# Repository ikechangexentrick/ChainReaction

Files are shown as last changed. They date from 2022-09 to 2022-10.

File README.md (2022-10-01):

# ChainReaction
8 step analog sequencer, including two variants of CV and Trigger.

## ChainReaction-Trigger

front view

### [schematic](https://raw.githubusercontent.com/ikechangexentrick/ChainReaction/master/ChainReaction_Trigger_v1.1_schematic.pdf)

## ChainReaction-CV

front view

### [schematic](https://raw.githubusercontent.com/ikechangexentrick/ChainReaction/master/ChainReaction_CV_v1.1_schematic.pdf)

# TBD

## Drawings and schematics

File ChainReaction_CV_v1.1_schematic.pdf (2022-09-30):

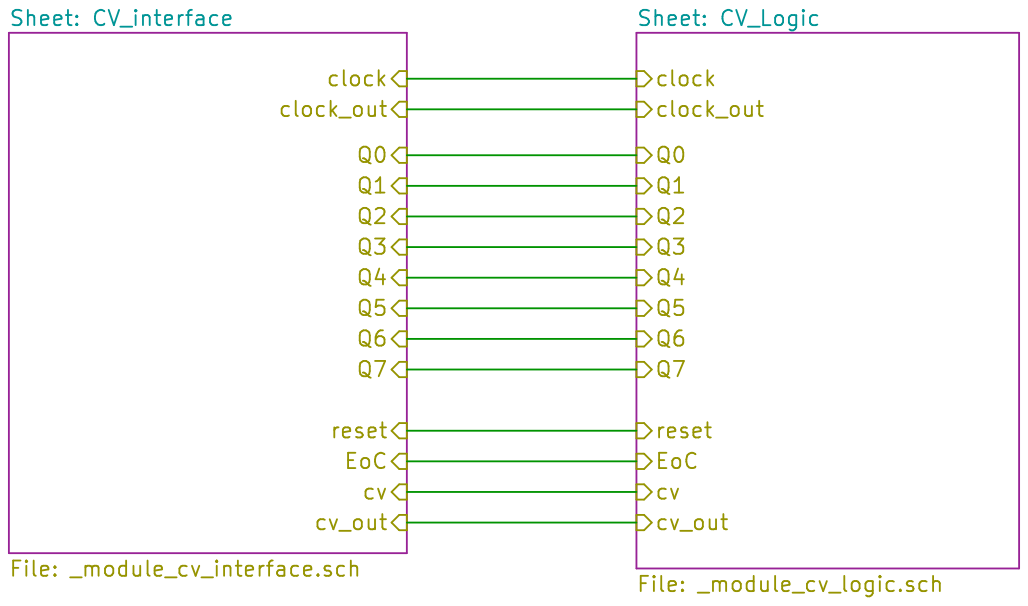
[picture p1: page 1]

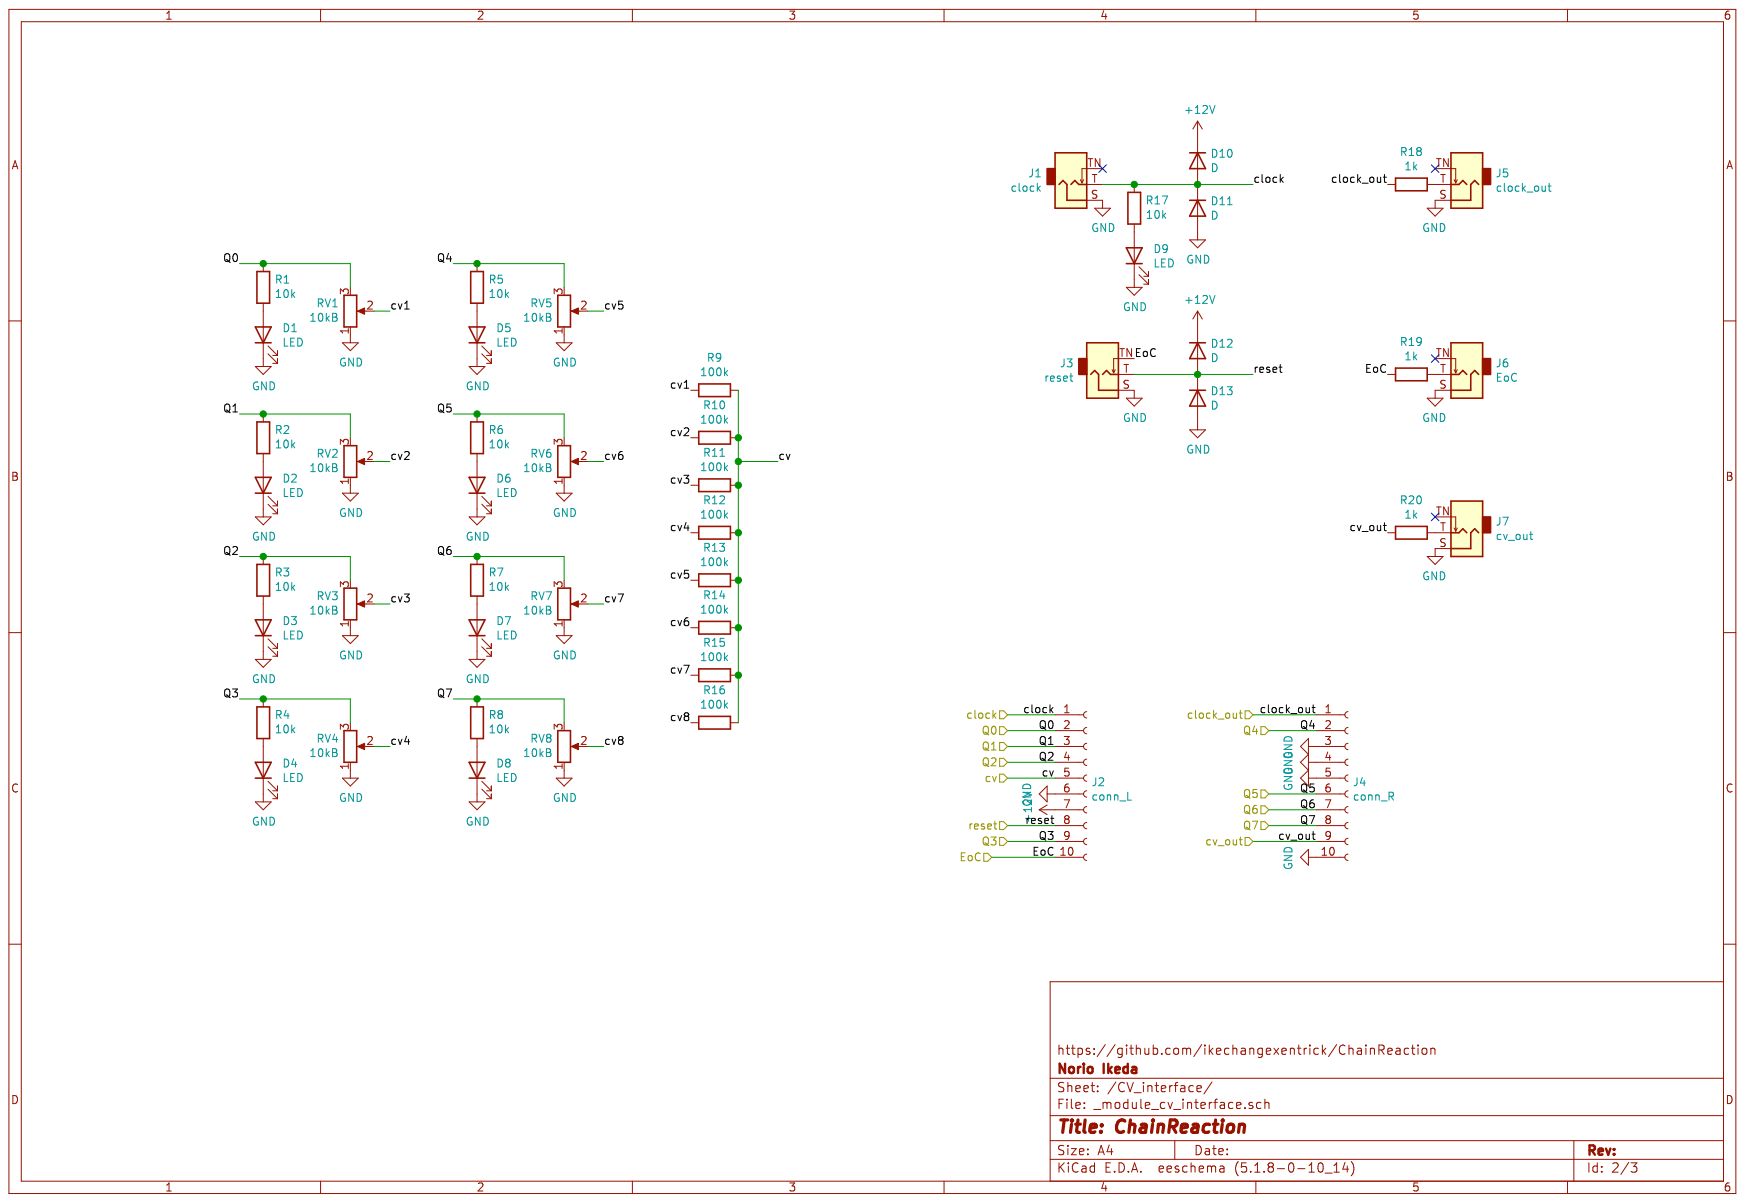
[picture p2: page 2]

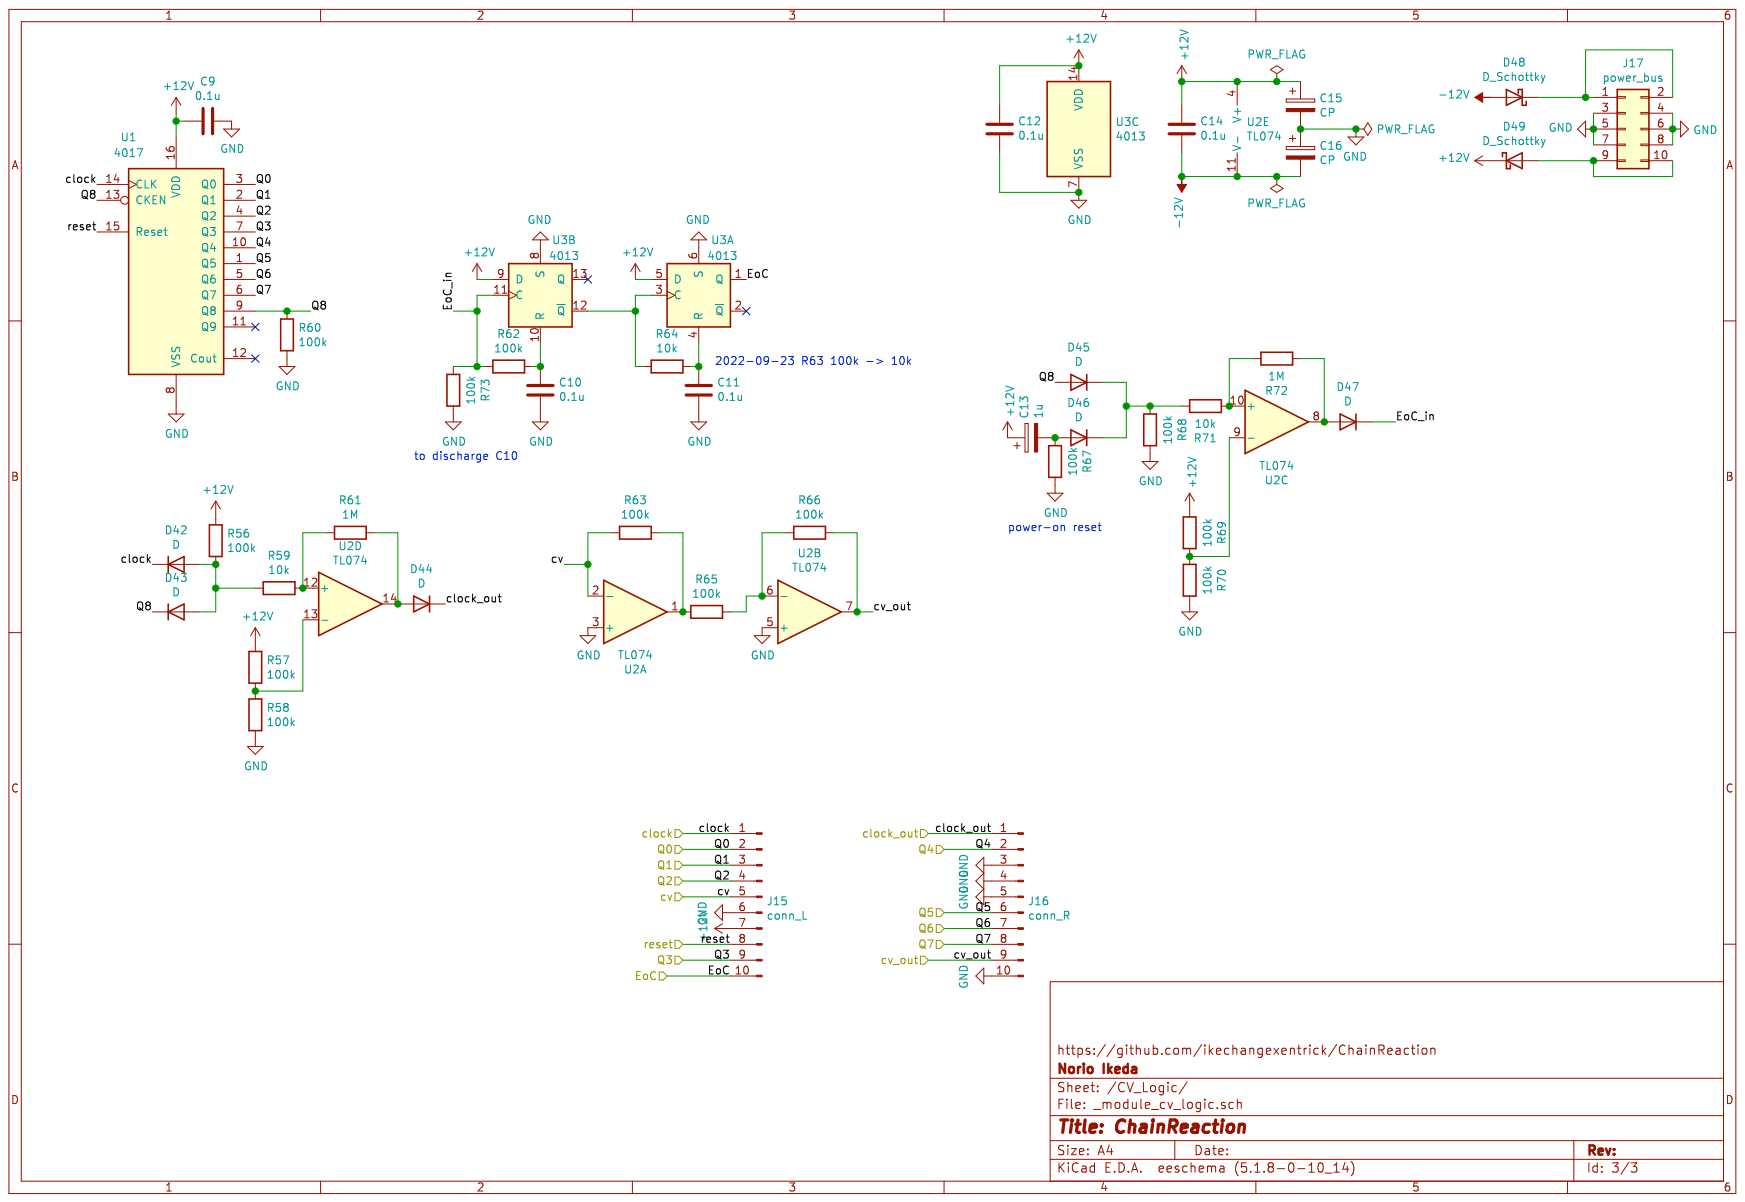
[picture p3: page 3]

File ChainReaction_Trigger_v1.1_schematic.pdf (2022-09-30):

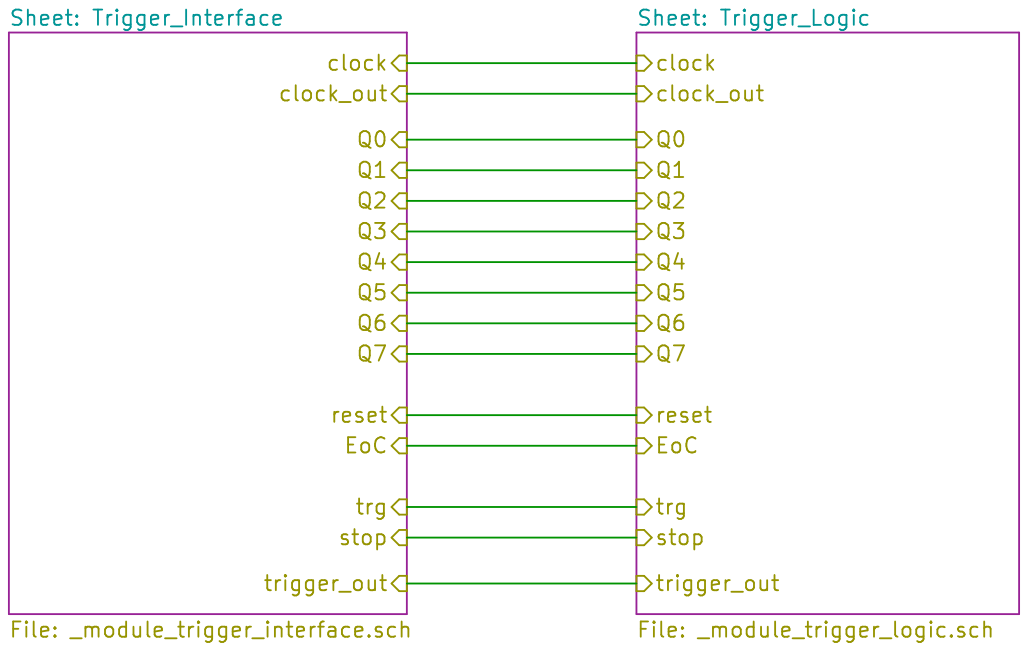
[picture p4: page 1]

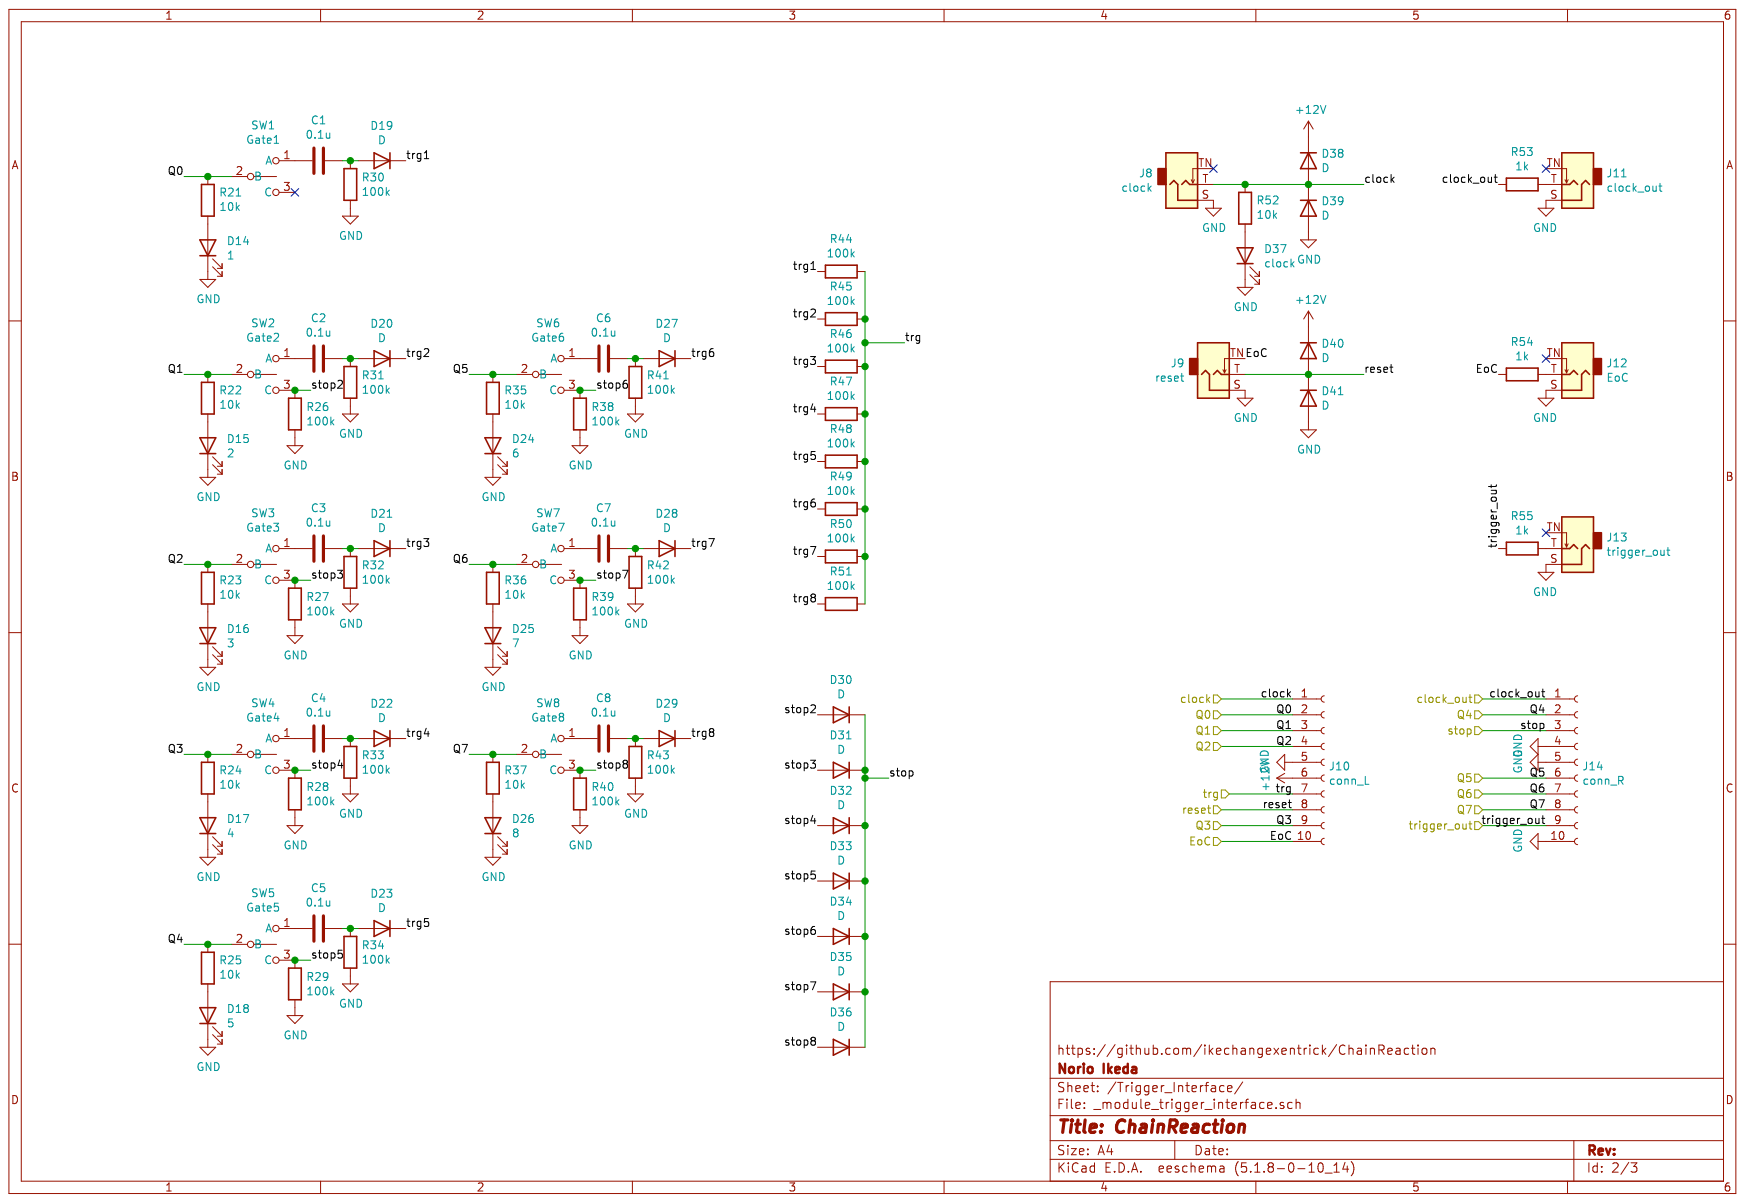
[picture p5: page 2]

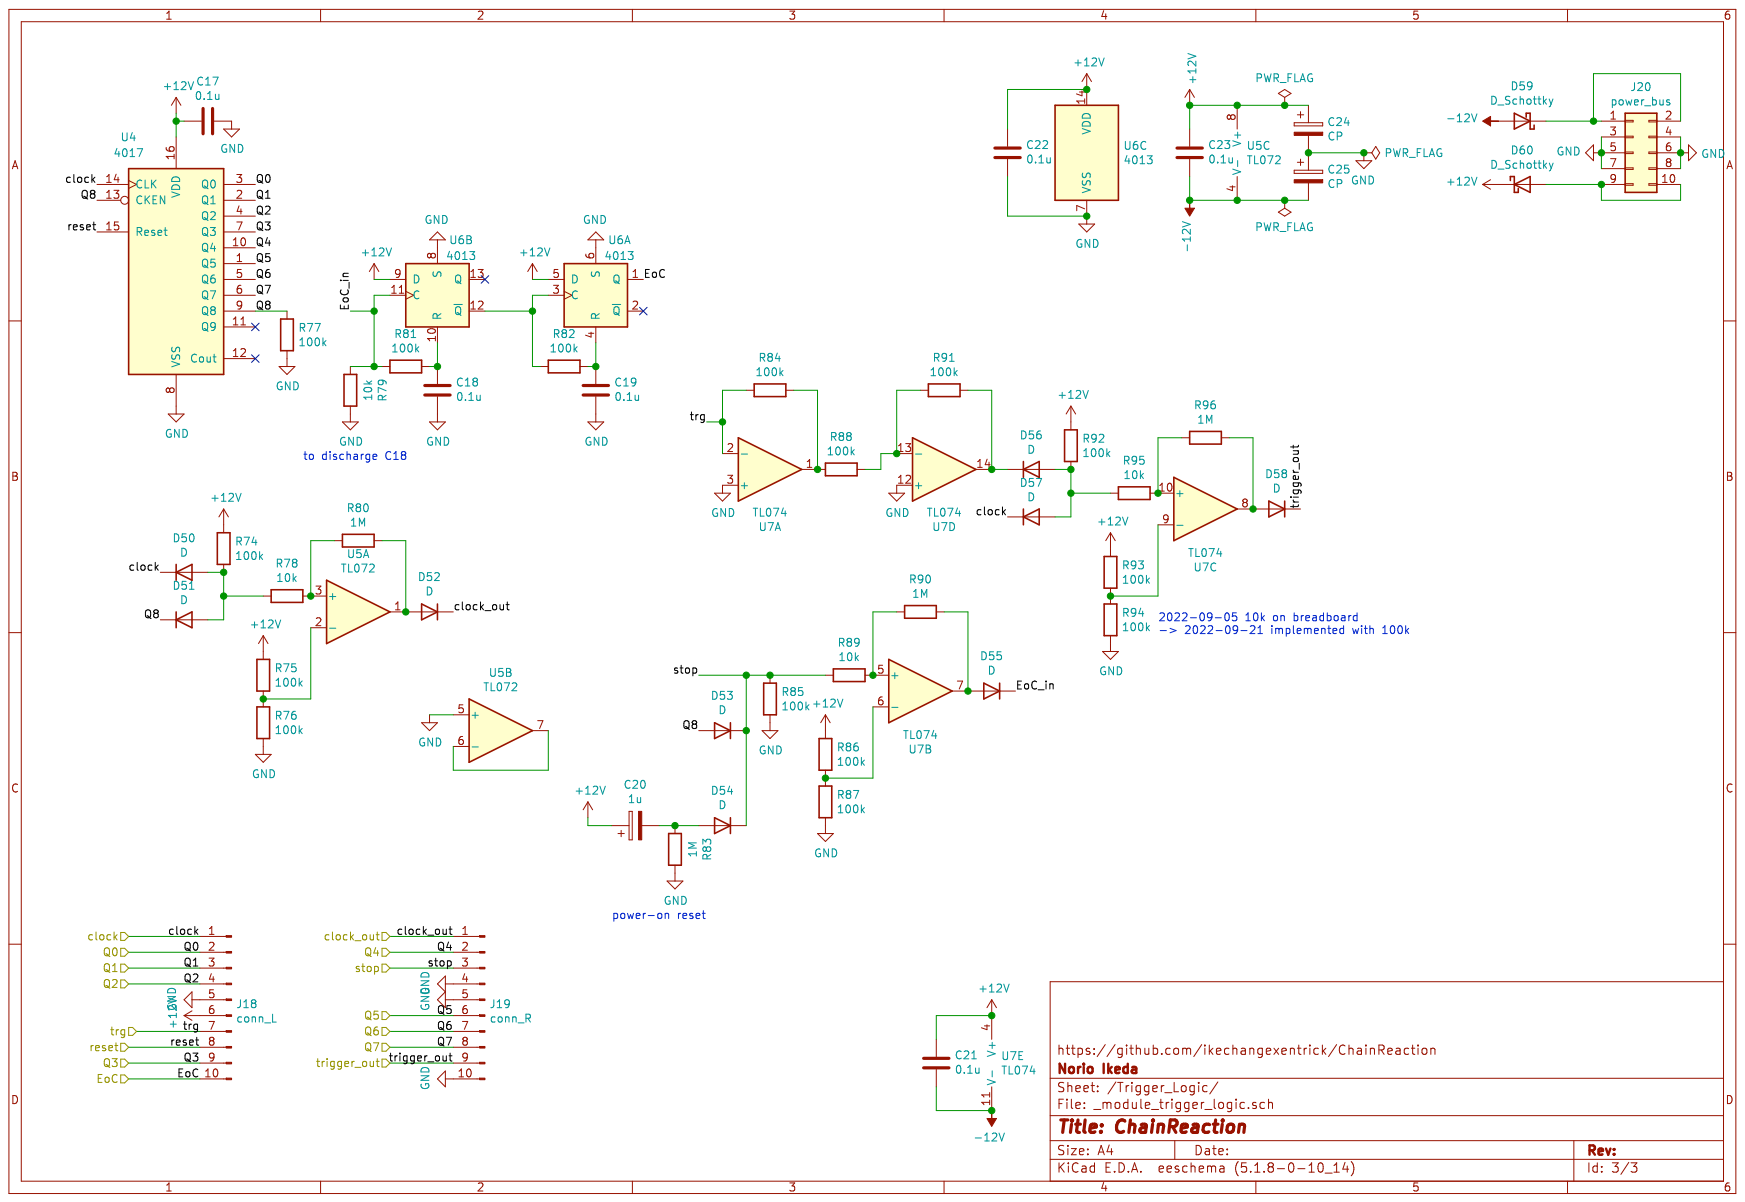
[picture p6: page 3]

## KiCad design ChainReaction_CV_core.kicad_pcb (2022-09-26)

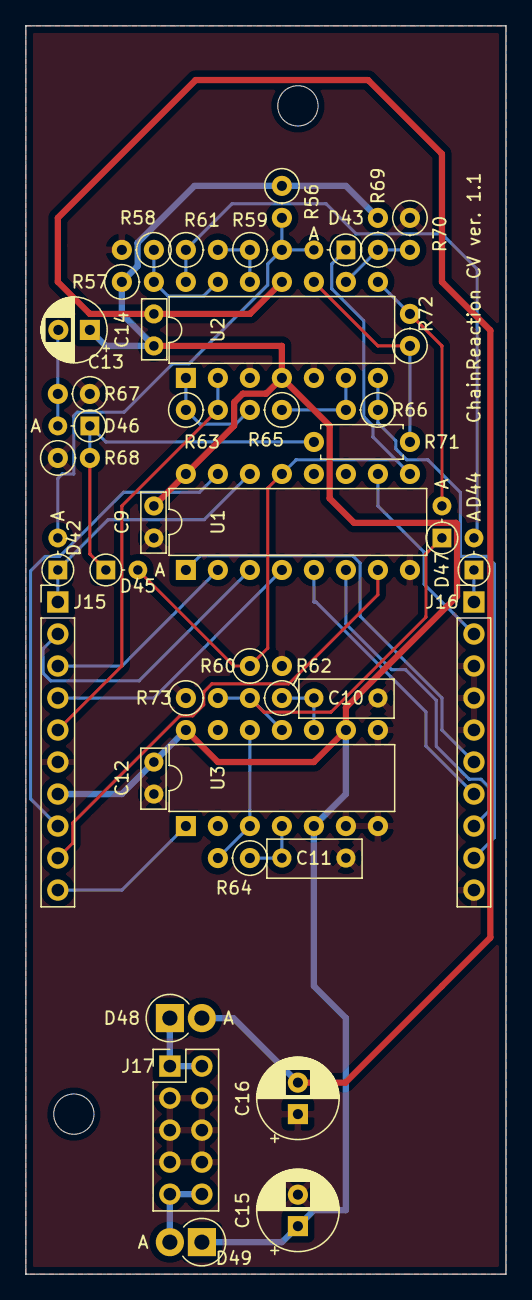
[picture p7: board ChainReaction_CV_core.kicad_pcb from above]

Board: 2 copper layers, 38.1 x 99.1 mm, 40 parts (0 on the bottom side), 35 nets.

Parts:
C9, C12, C14: 0.1u; C_Axial_L4.8mm_D2.0mm_P2.54mm_Horizontal
C10, C11: 0.1u; C_Axial_L4.8mm_D3.1mm_P5.08mm_Horizontal
C13: 1u; CP_Radial_D5.0mm_P2.50mm
C15, C16: CP; CP_Radial_D6.3mm_P2.50mm
D42, D43, D44, D45, D46, D47: D; D_DO-34_SOD68_P2.54mm_Vertical_AnodeUp
D48, D49: D_Schottky; D_DO-15_P2.54mm_Vertical_AnodeUp
J15: conn_L; PinHeader_1x10_P2.54mm_Vertical
J16: conn_R; PinHeader_1x10_P2.54mm_Vertical
J17: power_bus; PinHeader_2x05_P2.54mm_Vertical
R56, R57, R58, R60, R62, R63, R65, R66, R67, R68, R69, R70, R73: 100k; R_Axial_DIN0207_L6.3mm_D2.5mm_P2.54mm_Vertical
R59, R64: 10k; R_Axial_DIN0207_L6.3mm_D2.5mm_P2.54mm_Vertical
R61, R72: 1M; R_Axial_DIN0207_L6.3mm_D2.5mm_P2.54mm_Vertical
R71: 10k; R_Axial_DIN0207_L6.3mm_D2.5mm_P7.62mm_Horizontal
U1: 4017; DIP-16_W7.62mm
U2: TL074; DIP-14_W7.62mm
U3: 4013; DIP-14_W7.62mm

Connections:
+12V: C9.2, C12.2, C13.1, C14.2, C15.1, D49.1, J15.7, R56.1, R57.1, R69.2, U1.16, U2.4, U3.5, U3.9, U3.14
-12V: C14.1, C16.2, D48.2, U2.11
/CV_Logic/EoC: J15.10, U3.1
/CV_Logic/EoC_in: D47.1, R62.2, R73.2, U3.11
/CV_Logic/Q0: J15.2, U1.3
/CV_Logic/Q1: J15.3, U1.2
/CV_Logic/Q2: J15.4, U1.4
/CV_Logic/Q3: J15.9, U1.7
/CV_Logic/Q4: J16.2, U1.10
/CV_Logic/Q5: J16.6, U1.1
/CV_Logic/Q6: J16.7, U1.5
/CV_Logic/Q7: J16.8, U1.6
/CV_Logic/Q8: D43.1, D45.2, R60.1, U1.9, U1.13
/CV_Logic/clock: D42.1, J15.1, U1.14
/CV_Logic/clock_out: D44.1, J16.1
/CV_Logic/cv: J15.5, R63.2, U2.2
/CV_Logic/cv_out: J16.9, R66.1, U2.7
/CV_Logic/reset: J15.8, U1.15
GND: C9.1, C10.1, C11.1, C12.1, C15.2, C16.1, J15.6, J16.3, J16.4, J16.5, J16.10, J17.3, J17.4, J17.5, J17.6, J17.7, J17.8, R58.2, R60.2, R67.1, R68.1, R70.1, R73.1, U1.8, U2.3, U2.5, U3.6, U3.7, U3.8
unnamed: C10.2, R62.1, U3.10
unnamed: C11.2, R64.1, U3.4
unnamed: C13.2, D46.2, R67.2
unnamed: D42.2, D43.2, R56.2, R59.2
unnamed: D44.2, R61.1, U2.14
unnamed: D45.1, D46.1, R68.2, R71.1
unnamed: D47.2, R72.2, U2.8
unnamed: D48.1, J17.1, J17.2
unnamed: D49.2, J17.9, J17.10
unnamed: R57.2, R58.1, U2.13
unnamed: R59.1, R61.2, U2.12
unnamed: R63.1, R65.2, U2.1
unnamed: R64.2, U3.3, U3.12
unnamed: R65.1, R66.2, U2.6
unnamed: R69.1, R70.2, U2.9
unnamed: R71.2, R72.1, U2.10

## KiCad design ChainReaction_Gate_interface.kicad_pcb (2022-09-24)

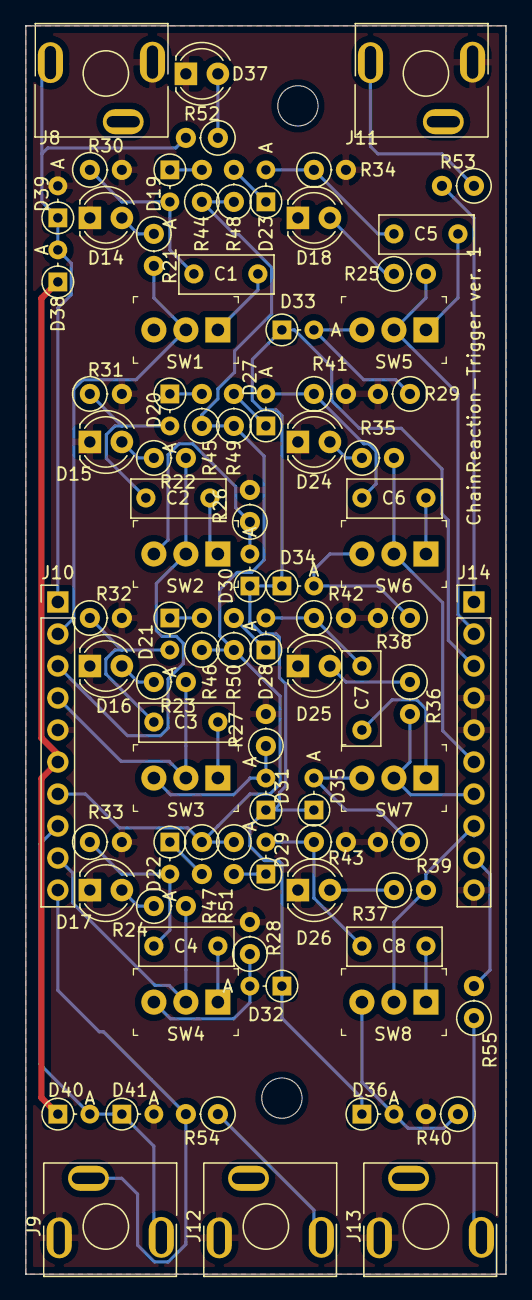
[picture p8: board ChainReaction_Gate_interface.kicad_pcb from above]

Board: 2 copper layers, 38.1 x 99.1 mm, 102 parts (0 on the bottom side), 60 nets.

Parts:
1, 2, 3, 4, 5, 6, 7, 8: MountingHole_4mm
C1, C2, C3, C4, C5, C6, C7, C8: 0.1u; C_Axial_L4.8mm_D3.1mm_P5.08mm_Horizontal
Clk out: annotation_3.5mm_jack_out
Clock: annotation_3.5mm_jack_in
D14: 1; LED_D4.0mm
D15: 2; LED_D4.0mm
D16: 3; LED_D4.0mm
D17: 4; LED_D4.0mm
D18: 5; LED_D4.0mm
D19, D20, D21, D22, D23, D27, D28, D29, D30, D31, D32, D33, D34, D35, D36, D38, D39, D40, D41: D; D_DO-34_SOD68_P2.54mm_Vertical_AnodeUp
D24: 6; LED_D4.0mm
D25: 7; LED_D4.0mm
D26: 8; LED_D4.0mm
D37: clock; LED_D4.0mm
EoC: annotation_3.5mm_jack_out
J8: clock; MJ-355_3.5mm_mono_jack
J9: reset; MJ-355_3.5mm_mono_jack
J10: conn_L; PinHeader_1x10_P2.54mm_Vertical
J11: clock_out; MJ-355_3.5mm_mono_jack
J12: EoC; MJ-355_3.5mm_mono_jack
J13: trigger_out; MJ-355_3.5mm_mono_jack
J14: conn_R; PinHeader_1x10_P2.54mm_Vertical
On-Off: MountingHole_5mm
On-Off-End: MountingHole_5mm
R21, R22, R23, R24, R25, R35, R36, R37, R52: 10k; R_Axial_DIN0207_L6.3mm_D2.5mm_P2.54mm_Vertical
R26, R27, R28, R29, R30, R31, R32, R33, R34, R38, R39, R40, R41, R42, R43, R44, R45, R46, R47, R48, R49, R50, R51: 100k; R_Axial_DIN0207_L6.3mm_D2.5mm_P2.54mm_Vertical
R53, R54, R55: 1k; R_Axial_DIN0207_L6.3mm_D2.5mm_P2.54mm_Vertical
Reset: annotation_3.5mm_jack_in
SW1: Gate1; Switch_Toggle_on-off-on_akizuki
SW2: Gate2; Switch_Toggle_on-off-on_akizuki
SW3: Gate3; Switch_Toggle_on-off-on_akizuki
SW4: Gate4; Switch_Toggle_on-off-on_akizuki
SW5: Gate5; Switch_Toggle_on-off-on_akizuki
SW6: Gate6; Switch_Toggle_on-off-on_akizuki
SW7: Gate7; Switch_Toggle_on-off-on_akizuki
SW8: Gate8; Switch_Toggle_on-off-on_akizuki
Trigger: annotation_3.5mm_jack_out
clock: MountingHole_4mm

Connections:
+12V: D38.1, D40.1, J10.6
/Trigger_Interface/EoC: J9.TN, J10.10, R54.2
/Trigger_Interface/Q0: J10.2, R21.2, SW1.2
/Trigger_Interface/Q1: J10.3, R22.2, SW2.2
/Trigger_Interface/Q2: J10.4, R23.2, SW3.2
/Trigger_Interface/Q3: J10.9, R24.2, SW4.2
/Trigger_Interface/Q4: J14.2, R25.2, SW5.2
/Trigger_Interface/Q5: J14.6, R35.2, SW6.2
/Trigger_Interface/Q6: J14.7, R36.2, SW7.2
/Trigger_Interface/Q7: J14.8, R37.2, SW8.2
/Trigger_Interface/clock: D38.2, D39.1, J8.T, J10.1, R52.2
/Trigger_Interface/clock_out: J14.1, R53.2
/Trigger_Interface/reset: D40.2, D41.1, J9.T, J10.8
/Trigger_Interface/stop: D30.1, D31.1, D32.1, D33.1, D34.1, D35.1, D36.1, J14.3
/Trigger_Interface/stop2: D30.2, R26.1, SW2.3
/Trigger_Interface/stop3: D31.2, R27.1, SW3.3
/Trigger_Interface/stop4: D32.2, R28.1, SW4.3
/Trigger_Interface/stop5: D33.2, R29.1, SW5.3
/Trigger_Interface/stop6: D34.2, R38.1, SW6.3
/Trigger_Interface/stop7: D35.2, R39.1, SW7.3
/Trigger_Interface/stop8: D36.2, R40.1, SW8.3
/Trigger_Interface/trg: J10.7, R44.1, R45.1, R46.1, R47.1, R48.1, R49.1, R50.1, R51.1
/Trigger_Interface/trg1: D19.1, R44.2
/Trigger_Interface/trg2: D20.1, R45.2
/Trigger_Interface/trg3: D21.1, R46.2
/Trigger_Interface/trg4: D22.1, R47.2
/Trigger_Interface/trg5: D23.1, R48.2
/Trigger_Interface/trg6: D27.1, R49.2
/Trigger_Interface/trg7: D28.1, R50.2
/Trigger_Interface/trg8: D29.1, R51.2
/Trigger_Interface/trigger_out: J14.9, R55.2
GND: D14.1, D15.1, D16.1, D17.1, D18.1, D24.1, D25.1, D26.1, D37.1, D39.2, D41.2, J8.S, J9.S, J10.5, J11.S, J12.S, J13.S, J14.4, J14.5, J14.10, R26.2, R27.2, R28.2, R29.2, R30.2, R31.2, R32.2, R33.2, R34.2, R38.2, R39.2, R40.2, R41.2, R42.2, R43.2
unnamed: C1.1, SW1.1
unnamed: C1.2, D19.2, R30.1
unnamed: C2.1, SW2.1
unnamed: C2.2, D20.2, R31.1
unnamed: C3.1, SW3.1
unnamed: C3.2, D21.2, R32.1
unnamed: C4.1, SW4.1
unnamed: C4.2, D22.2, R33.1
unnamed: C5.1, SW5.1
unnamed: C5.2, D23.2, R34.1
unnamed: C6.1, SW6.1
unnamed: C6.2, D27.2, R41.1
unnamed: C7.1, SW7.1
unnamed: C7.2, D28.2, R42.1
unnamed: C8.1, SW8.1
unnamed: C8.2, D29.2, R43.1
unnamed: D14.2, R21.1
unnamed: D15.2, R22.1
unnamed: D16.2, R23.1
unnamed: D17.2, R24.1
unnamed: D18.2, R25.1
unnamed: D24.2, R35.1
unnamed: D25.2, R36.1
unnamed: D26.2, R37.1
unnamed: D37.2, R52.1
unnamed: J11.T, R53.1
unnamed: J12.T, R54.1
unnamed: J13.T, R55.1

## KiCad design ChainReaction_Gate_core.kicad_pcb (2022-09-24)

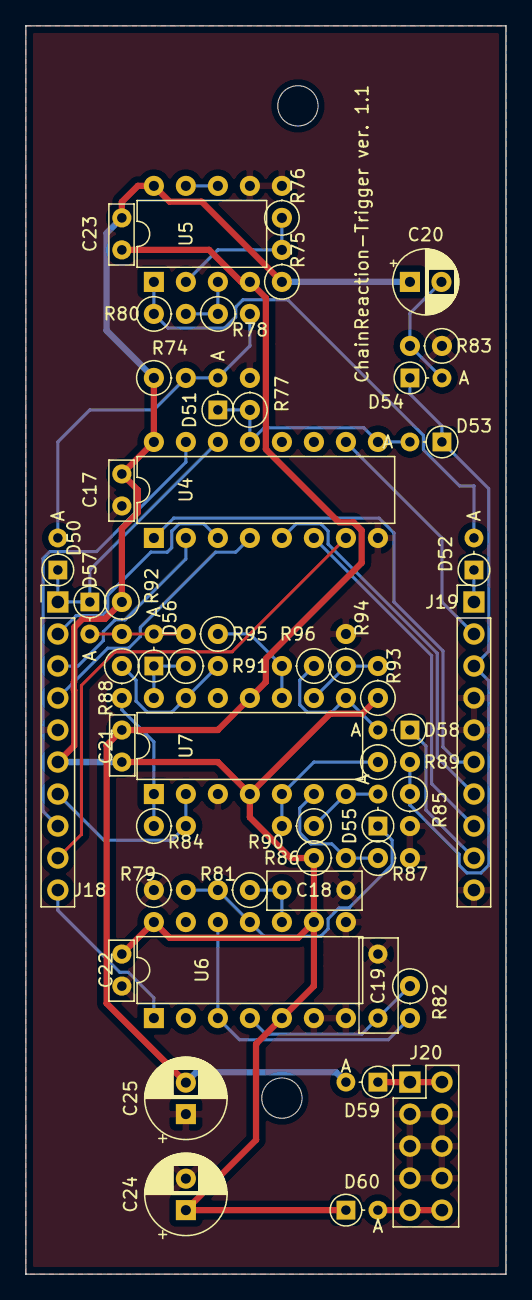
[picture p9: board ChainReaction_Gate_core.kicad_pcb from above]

Board: 2 copper layers, 38.1 x 99.1 mm, 50 parts (0 on the bottom side), 41 nets.

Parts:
C17, C21, C22, C23: 0.1u; C_Axial_L4.8mm_D2.0mm_P2.54mm_Horizontal
C18, C19: 0.1u; C_Axial_L4.8mm_D3.1mm_P5.08mm_Horizontal
C20: 1u; CP_Radial_D5.0mm_P2.50mm
C24, C25: CP; CP_Radial_D6.3mm_P2.50mm
D50, D51, D52, D53, D54, D55, D56, D57, D58: D; D_DO-34_SOD68_P2.54mm_Vertical_AnodeUp
D59, D60: D_Schottky; D_DO-34_SOD68_P2.54mm_Vertical_AnodeUp
J18: conn_L; PinHeader_1x10_P2.54mm_Vertical
J19: conn_R; PinHeader_1x10_P2.54mm_Vertical
J20: power_bus; PinHeader_2x05_P2.54mm_Vertical
R74, R75, R76, R77, R81, R82, R84, R85, R86, R87, R88, R91, R92, R93, R94: 100k; R_Axial_DIN0207_L6.3mm_D2.5mm_P2.54mm_Vertical
R78, R79, R89, R95: 10k; R_Axial_DIN0207_L6.3mm_D2.5mm_P2.54mm_Vertical
R80, R83, R90, R96: 1M; R_Axial_DIN0207_L6.3mm_D2.5mm_P2.54mm_Vertical
U4: 4017; DIP-16_W7.62mm
U5: TL072; DIP-8_W7.62mm
U6: 4013; DIP-14_W7.62mm
U7: TL074; DIP-14_W7.62mm

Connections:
+12V: C17.2, C20.1, C21.2, C22.2, C23.2, C24.1, D60.1, J18.6, R74.1, R75.1, R86.1, R92.1, R93.1, U4.16, U5.8, U6.5, U6.9, U6.14, U7.4
-12V: C21.1, C23.1, C25.2, D59.2, U5.4, U7.11
/Trigger_Logic/EoC: J18.10, U6.1
/Trigger_Logic/EoC_in: D55.1, R79.2, R81.2, U6.11
/Trigger_Logic/Q0: J18.2, U4.3
/Trigger_Logic/Q1: J18.3, U4.2
/Trigger_Logic/Q2: J18.4, U4.4
/Trigger_Logic/Q3: J18.9, U4.7
/Trigger_Logic/Q4: J19.2, U4.10
/Trigger_Logic/Q5: J19.6, U4.1
/Trigger_Logic/Q6: J19.7, U4.5
/Trigger_Logic/Q7: J19.8, U4.6
/Trigger_Logic/Q8: D51.1, D53.2, R77.1, U4.9, U4.13
/Trigger_Logic/clock: D50.1, D57.1, J18.1, U4.14
/Trigger_Logic/clock_out: D52.1, J19.1
/Trigger_Logic/reset: J18.8, U4.15
/Trigger_Logic/stop: D53.1, D54.1, J19.3, R85.1, R89.2
/Trigger_Logic/trg: J18.7, R84.2, U7.2
/Trigger_Logic/trigger_out: D58.1, J19.9
GND: C17.1, C18.1, C19.1, C22.1, C24.2, C25.1, J18.5, J19.4, J19.5, J19.10, J20.3, J20.4, J20.5, J20.6, J20.7, J20.8, R76.2, R77.2, R79.1, R83.1, R85.2, R87.2, R94.2, U4.8, U5.5, U6.6, U6.7, U6.8, U7.3, U7.12
unnamed: C18.2, R81.1, U6.10
unnamed: C19.2, R82.1, U6.4
unnamed: C20.2, D54.2, R83.2
unnamed: D50.2, D51.2, R74.2, R78.2
unnamed: D52.2, R80.1, U5.1
unnamed: D55.2, R90.1, U7.7
unnamed: D56.1, R91.1, U7.14
unnamed: D56.2, D57.2, R92.2, R95.2
unnamed: D58.2, R96.1, U7.8
unnamed: D59.1, J20.1, J20.2
unnamed: D60.2, J20.9, J20.10
unnamed: R75.2, R76.1, U5.2
unnamed: R78.1, R80.2, U5.3
unnamed: R82.2, U6.3, U6.12
unnamed: R84.1, R88.2, U7.1
unnamed: R86.2, R87.1, U7.6
unnamed: R88.1, R91.2, U7.13
unnamed: R89.1, R90.2, U7.5
unnamed: R93.2, R94.1, U7.9
unnamed: R95.1, R96.2, U7.10
unnamed: U5.6, U5.7

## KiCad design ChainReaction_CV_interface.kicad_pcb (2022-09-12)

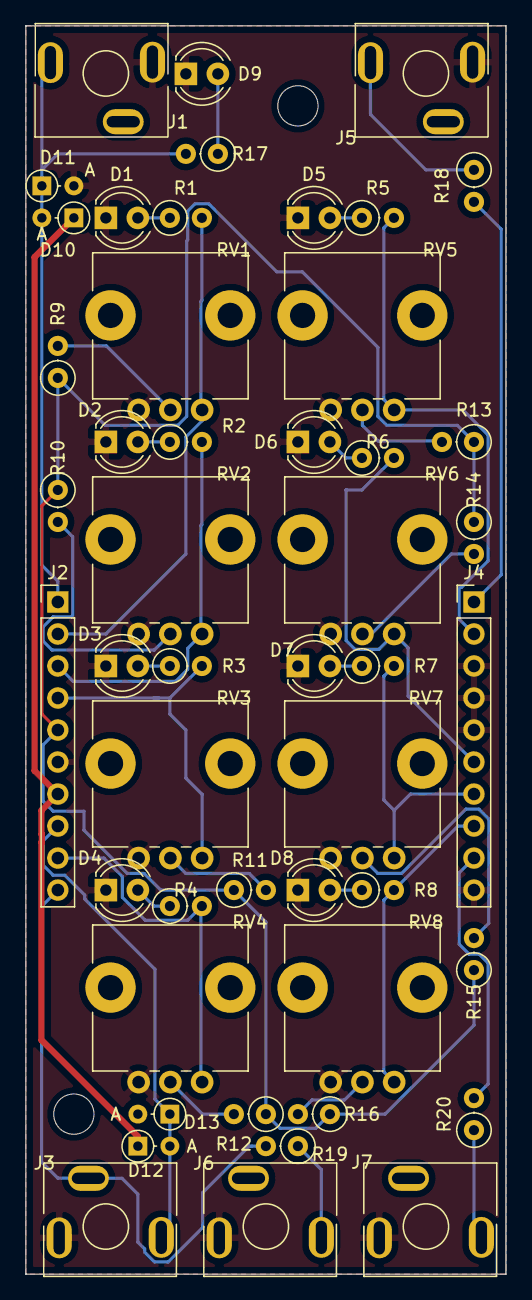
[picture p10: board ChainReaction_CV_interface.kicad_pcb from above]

Board: 2 copper layers, 38.1 x 99.1 mm, 61 parts (0 on the bottom side), 36 nets.

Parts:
1, 2, 3, 4, 5, 6, 7, 8: MountingHole_4mm
CV: annotation_3.5mm_jack_out
Clk out: annotation_3.5mm_jack_out
Clock: annotation_3.5mm_jack_in
D1, D2, D3, D4, D5, D6, D7, D8, D9: LED; LED_D4.0mm
D10, D11, D12, D13: D; D_DO-34_SOD68_P2.54mm_Vertical_AnodeUp
EoC: annotation_3.5mm_jack_out
J1: clock; MJ-355_3.5mm_mono_jack
J2: conn_L; PinHeader_1x10_P2.54mm_Vertical
J3: reset; MJ-355_3.5mm_mono_jack
J4: conn_R; PinHeader_1x10_P2.54mm_Vertical
J5: clock_out; MJ-355_3.5mm_mono_jack
J6: EoC; MJ-355_3.5mm_mono_jack
J7: cv_out; MJ-355_3.5mm_mono_jack
R1, R2, R3, R4, R5, R6, R7, R8, R17: 10k; R_Axial_DIN0207_L6.3mm_D2.5mm_P2.54mm_Vertical
R9, R10, R11, R12, R13, R14, R15, R16: 100k; R_Axial_DIN0207_L6.3mm_D2.5mm_P2.54mm_Vertical
R18, R19, R20: 1k; R_Axial_DIN0207_L6.3mm_D2.5mm_P2.54mm_Vertical
RV1, RV2, RV3, RV4, RV5, RV6, RV7, RV8: 10kB; Potentiometer_Alps_RK09L_Single_Vertical
Reset: annotation_3.5mm_jack_in

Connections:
+12V: D10.1, D12.1, J2.7
/CV_interface/EoC: J2.10, J3.TN, R19.2
/CV_interface/Q0: J2.2, R1.2, RV1.3
/CV_interface/Q1: J2.3, R2.2, RV2.3
/CV_interface/Q2: J2.4, R3.2, RV3.3
/CV_interface/Q3: J2.9, R4.2, RV4.3
/CV_interface/Q4: J4.2, R5.2, RV5.3
/CV_interface/Q5: J4.6, R6.2, RV6.3
/CV_interface/Q6: J4.7, R7.2, RV7.3
/CV_interface/Q7: J4.8, R8.2, RV8.3
/CV_interface/clock: D10.2, D11.1, J1.T, J2.1, R17.2
/CV_interface/clock_out: J4.1, R18.2
/CV_interface/cv: J2.5, R9.1, R10.1, R11.1, R12.1, R13.1, R14.1, R15.1, R16.1
/CV_interface/cv1: R9.2, RV1.2
/CV_interface/cv2: R10.2, RV2.2
/CV_interface/cv3: R11.2, RV3.2
/CV_interface/cv4: R12.2, RV4.2
/CV_interface/cv5: R13.2, RV5.2
/CV_interface/cv6: R14.2, RV6.2
/CV_interface/cv7: R15.2, RV7.2
/CV_interface/cv8: R16.2, RV8.2
/CV_interface/cv_out: J4.9, R20.2
/CV_interface/reset: D12.2, D13.1, J2.8, J3.T
GND: D1.1, D2.1, D3.1, D4.1, D5.1, D6.1, D7.1, D8.1, D9.1, D11.2, D13.2, J1.S, J2.6, J3.S, J4.3, J4.4, J4.5, J4.10, J5.S, J6.S, J7.S, RV1.1, RV2.1, RV3.1, RV4.1, RV5.1, RV6.1, RV7.1, RV8.1
unnamed: D1.2, R1.1
unnamed: D2.2, R2.1
unnamed: D3.2, R3.1
unnamed: D4.2, R4.1
unnamed: D5.2, R5.1
unnamed: D6.2, R6.1
unnamed: D7.2, R7.1
unnamed: D8.2, R8.1
unnamed: D9.2, R17.1
unnamed: J5.T, R18.1
unnamed: J6.T, R19.1
unnamed: J7.T, R20.1

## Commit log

2022-09-12 8 step analog sequencer "ChainReaction". There are two variants included; CV and Trigger.
    [ChainReaction.kicad_pcb, ChainReaction.sch, ChainReaction_CV.sch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]
2022-09-24 Fixed problems: - added power-on reset function - added 100ks to discharge caps with FFs(4013) - only for the CV; adjusted the parameter (100k -> 10k) of a resistor with a FF
    [ChainReaction_CV_core.kicad_pcb, ChainReaction_Gate_core.kicad_pcb, ChainReaction_Gate_interface.kicad_pcb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]
2022-09-26 adjusted some silks.
    [ChainReaction_CV_core.kicad_pcb]
2022-09-30 Added schematics.
    [ChainReaction.sch, ChainReaction_CV.sch, ChainReaction_Gate.sch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]
